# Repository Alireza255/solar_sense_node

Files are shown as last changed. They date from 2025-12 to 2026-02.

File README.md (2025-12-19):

# 🌞 Solar Sense Node

A **portable solar measuremnet unit** designed to work alongside **IV-curve tracing systems**, providing accurate environmental and panel-related measurements that complement **IV-curve tracing systems**.

This device wirelessly transmits real-time measurement data to a **IV-curve tracer unit**, enabling accurate data interpretation.

---

## 🚀 Project Overview

Accurate IV-curve measurement of solar panels requires precise knowledge of environmental conditions at the time of measurement. This project addresses that need by introducing a **dedicated wireless solar sensor module** that:

* Measures **solar irradiance** directly at the panel location
* Monitors **solar panel temperature**
* Determines **panel tilt angle**
* Sends all collected data wirelessly to the IV-curve measurement device

---

## 🔧 Measured Parameters

| Parameter | Description |
| --- | --- |
| ☀️ Solar Irradiance | Measures incident solar power for accurate performance normalization |
| 🌡️ Panel Temperature | Captures real-time module temperature for IV-curve correction |
| 📐 Tilt Angle | Determines panel orientation relative to the horizon |

---

## 🎯 Design Goals

* ✔️ High measurement accuracy
* ✔️ Low power consumption
* ✔️ Robust outdoor operation
* ✔️ Simple to use
* ✔️ Seamless integration with the IV-curve tracer developed by the team

---

## 🧪 Use Cases

* Solar panel characterization and testing
* PV system diagnostics
* Performance comparison under varying environmental conditions

---

## 🏫 Research & Development

This project is being developed by researchers at:

**University of Tehran**
**IV Curve Research Group**

The work aims to advance **practical, field-deployable measurement tools** for photovoltaic research and industrial applications.

---

## 📌 Project Status

> 🚧 **Under active development**
> Hardware design, firmware development, and system integration are currently in progress.

---

## 📜 License

This project is intended for **research and academic use**. Licensing details will be added in future releases.

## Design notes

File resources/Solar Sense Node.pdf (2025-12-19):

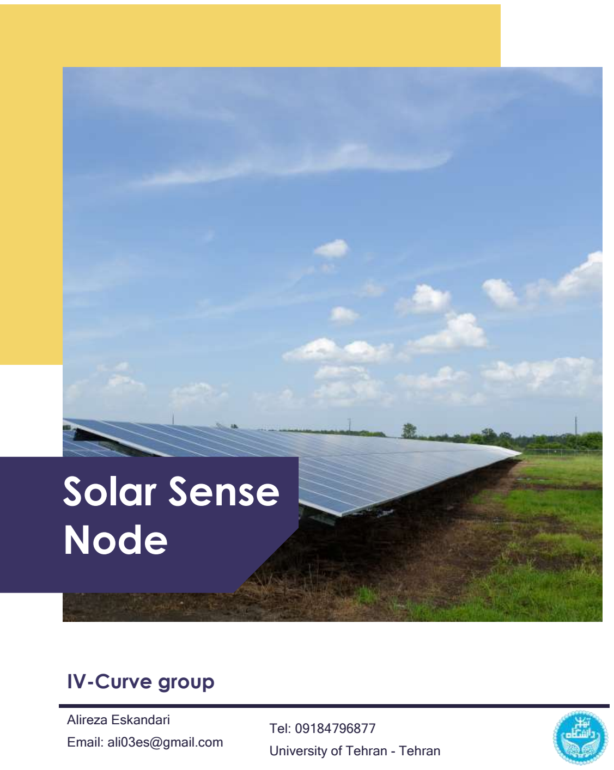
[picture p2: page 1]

# Solar Sense Node

## IV-Curve group

Alireza Eskandari

Email: ali03es@gmail.com

Tel: 09184796877

University of Tehran - Tehran

2

# DESIGN SPECIFICATIONS

1. Battery powered
2. Fully portable
3. Battery life 8 hours or longer
4. The ability to measure solar panel temperature
5. The ability to measure solar panel inclination
6. The ability to measure solar irradiance
7. Transmit telemetry data to the main device or a computer
8. Wireless link range 100 meters or greater
Spec | Solar 03 | Proposed solution
Battery life | 24hours | 30hours or higher
Tilt angle range & accuracy | 1˚-90˚ ±(1.0% + 1°) | 1˚-90˚ ±1˚
Module temperature range & accuracy | -40.0°C -99.9°C ±(1.0% + 1°C) | -55°C to +125°C ±0.5°C
Irradiance sensor range & accuracy | 0-1400 W m² ±(1.0% + 3dgt) | To be determined

The following report illustrates the different parts of the project and why each one was selected.

In addition to the information presented in this document, the link to the GitHub page of the project can be found here (https://github.com/Alireza255/solar_sense_node) and below.

github.com/Alireza255/solar_sense_node

3

Choosing a box

The sensor box, being a portable device, requires a box with a form factor that suits the

portable nature of the device.

The proposed box after careful research can be seen in the picture below:

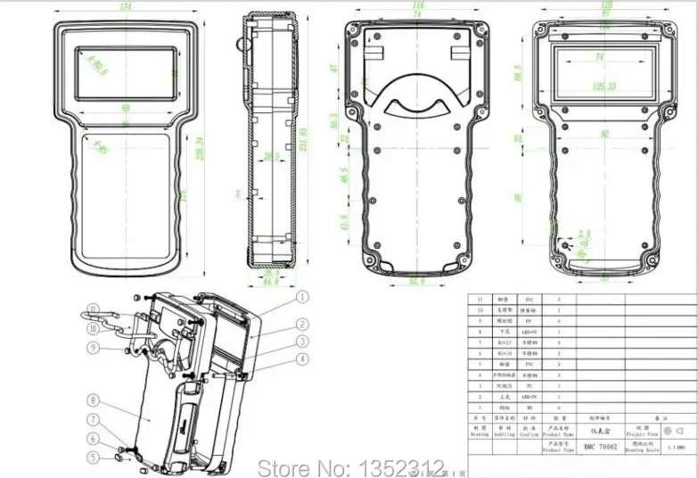
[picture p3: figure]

Mechanical specifications:

- Material: ABS plastic
- Overall dimensions: 238 × 134 × 58 mm
- Weight: 310 g (excluding screws)
- Front panel cutout size: 88 × 44 mm

The ability to implement a screen and also buttons for user interface. There are also

designated flat spots on the top and bottom for mounting connectors.

4

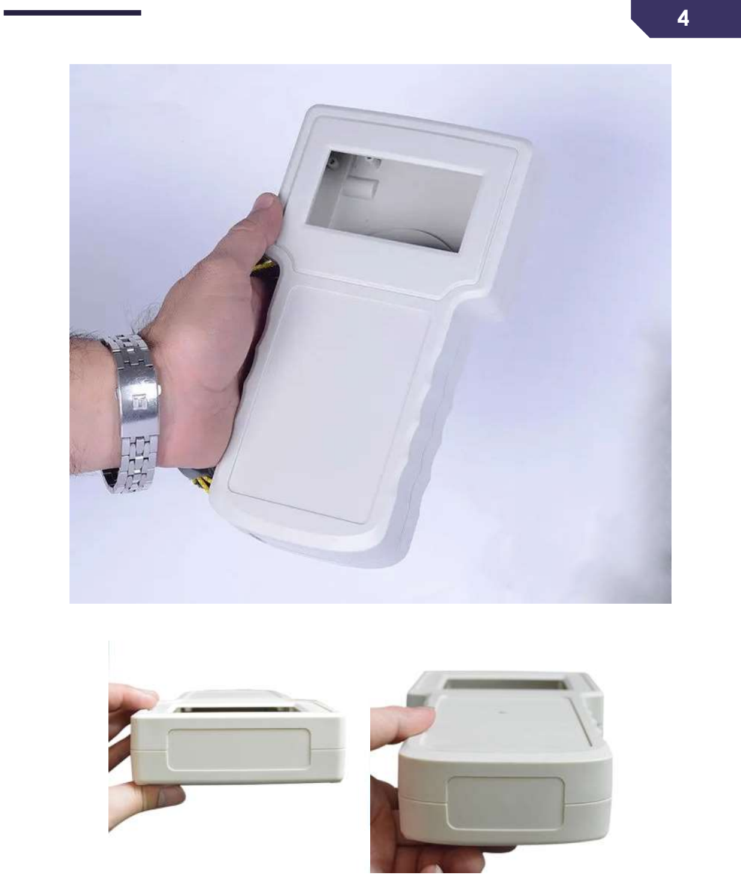
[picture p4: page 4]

5

Choosing a wireless link

After careful consideration of the constraints and available options. LoRa was chosen for

communication between the sensor box and the main box.

Why LoRa Was Selected

The sensor box system is battery powered and requires maximum wireless range and high

reliability under all environmental conditions. LoRa was selected because it provides

exceptional range while operating at very low power levels. Using chirp spread spectrum

modulation, LoRa maintains reliable communication over long distances, including non-line-

of-sight and interference-prone environments.

Unlike short-range technologies, LoRa is optimized for low data rate, low duty-cycle sensor

applications, allowing long battery life without sacrificing range.

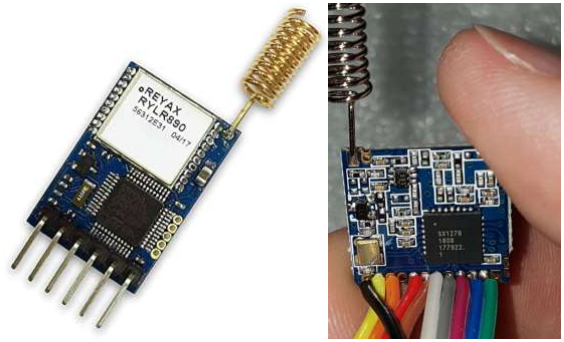
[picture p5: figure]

A comparison is made in the following table to illustrate the differences between the different

communication links that are available for this application and why LoRa is the best for our

application.

6

Technology | Typical Range | Power
| | Consumption
Data Rate | Notes
LoRa | 500m–15 km | Very Low | Very Low | High link budget, robust in harsh environments
Bluetooth | 10–100 m | Very Low | Medium | Short range, sensitive to obstacles
Zigbee | 50–200 m | Low | Low | Mesh required for long range
Wi-Fi | 50–100 m | High | High | Not suitable for battery operation
Sub-GHz FSK | 300–1000 m | Low–Medium | Low | Lower sensitivity than LoRa
Cellular | km+ | Medium–High | Medium | Requires SIM and network dependent

It is important to note that the low data rate of the LoRa protocol will never be an issue

because the amount of data that needs to be transmitted is extremely small.

Choosing a microcontroller

ARM microcontrollers, specifically those from ST-Microelectronics are very well suited for

portable applications due to their low power requirements. Another reason being that ST

offers a wide range of different microcontrollers (MCUs) for almost any application.

Research by the author indicates that microcontrollers with built-in radio links exist and

considering the requirements of the project, STM32WLE5CCU6 stands out as the perfect

choice as it includes LoRa out of the box.

This eliminates the need to add a different module on the board, simplifying the design and

freeing up more room for other components.

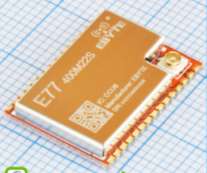
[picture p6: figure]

Ready-made modules are available which already include

everything that is needed to run the microcontroller.

This will greatly simplify the design process.

7

Communication Antenna

Any radio link needs an antenna and LoRa is no exception. In general, two different types of

antennae are suitable for our application, both of which can be seen in the figures below.

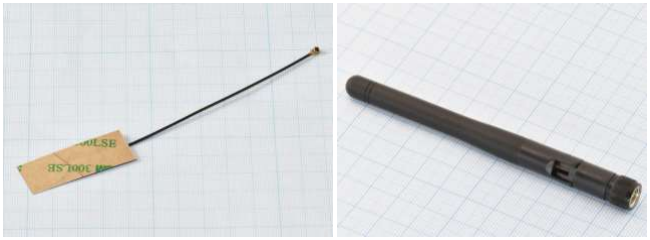
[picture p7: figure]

The antenna on the left is a patch antenna which can be installed within the device encloser

itself while the antenna on the right is a monopole antenna. Both designed for 433MHz.

One drawback to the patch antenna is directionality. Which tends to be more focused in patch

antennae. This makes communication harder since the orientation of the transmitter and

reciver in relation to one another might not be ideal.

- While the benfit of the patch antenna is clear, testing with both antenna might be

required in order to determine if the patch antenna is sufficient or not.

Power supply

In order to increase efficiency and improve battery life, great emphasis was put on having

only one supply rail in the entire device and since the MCU, wireless link and most of the

other components are powered by 3.3V, a decision was made from the very start to choose

the remaining components in such a way that they will also be powered from 3.3V.

Regulating the battery voltage down to 3.3V using a linear regulator was chosen because of

its simplicity and also the absence of much benefits if the design was to use a switching

regulator.

Choosing the right regulator required careful consideration of multiple factors, one of them

being the quiescent current which is a measure of the current draw when the output current of

8

the regulator is zero. This is extremely important as a low current draw when the micro

controller is in sleep mode will mean a higher battery life when the device is not in use.

Now a question might arise; Why not just use a switch to allow the user to turn off the device?

The answer lies in the real-time-clock of the microcontroller, which keeps time and date at the

expense of a few uA of current. Safe to say it is completely worth it.

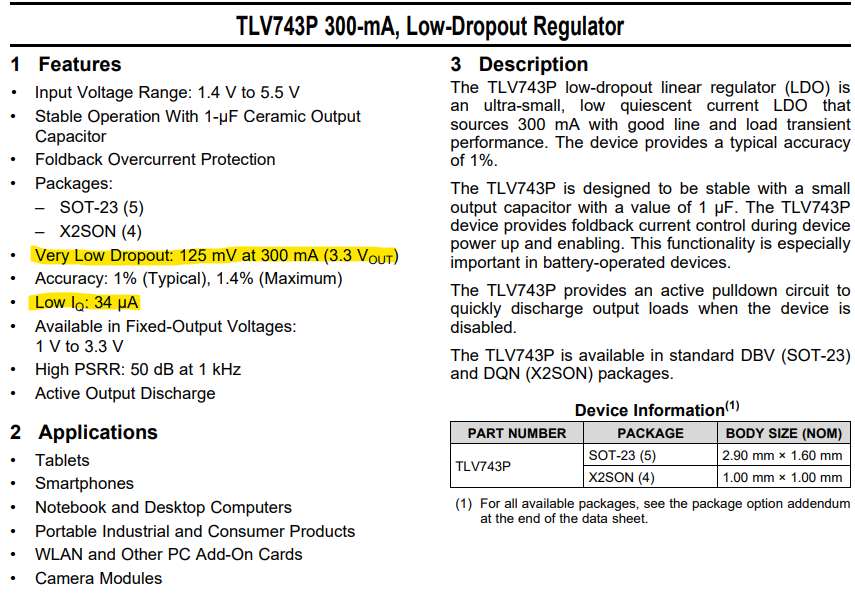
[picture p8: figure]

The chosen regulator can be seen on the picture above. This comes with the benefit of

allowing the microcontroller to turn the regulator off which means we can turn sensors or any

other parts of the circuit when needed to reduce power draw.

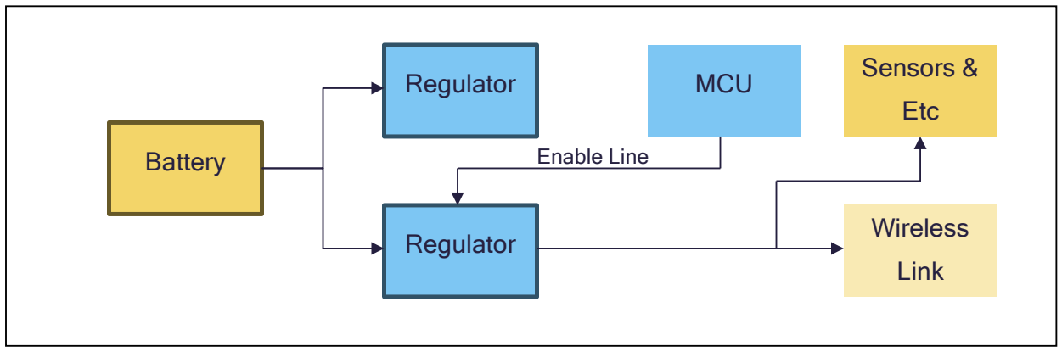
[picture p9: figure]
Battery; Regulator; MCU; Sensors &; Etc; Wireless; Link; Enable Line

9

Battery and charging

Lithium polymer batteries in the common size 18650 were chosen to power the device due to

their commonality.

Flat cells can also be used if the project runs into space

constraints, which is unlikely.

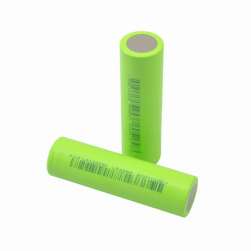
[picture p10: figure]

Charging the battery will be done using a USB-C Li-Po battery charger module which will also

provide the necessary voltage and current protections such as over-current, over-voltage and

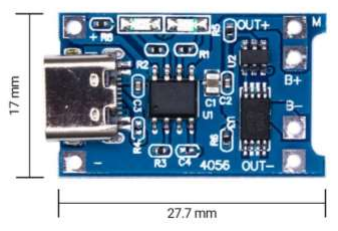
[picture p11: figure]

under-voltage protection.

An off the shelf, proven solution was

chosen instead of developing one from

scratch, saving on time and increasing

reliability.

Panel temperature sensor(s)

An interesting approach to panel temperature measurement was chosen. Instead of using

analog sensors and having to deal with accuracy problems of analog circuits, noise

susceptibility and most importantly and the current draw of analog sensors, the decision was

made to use digital sensors.

10

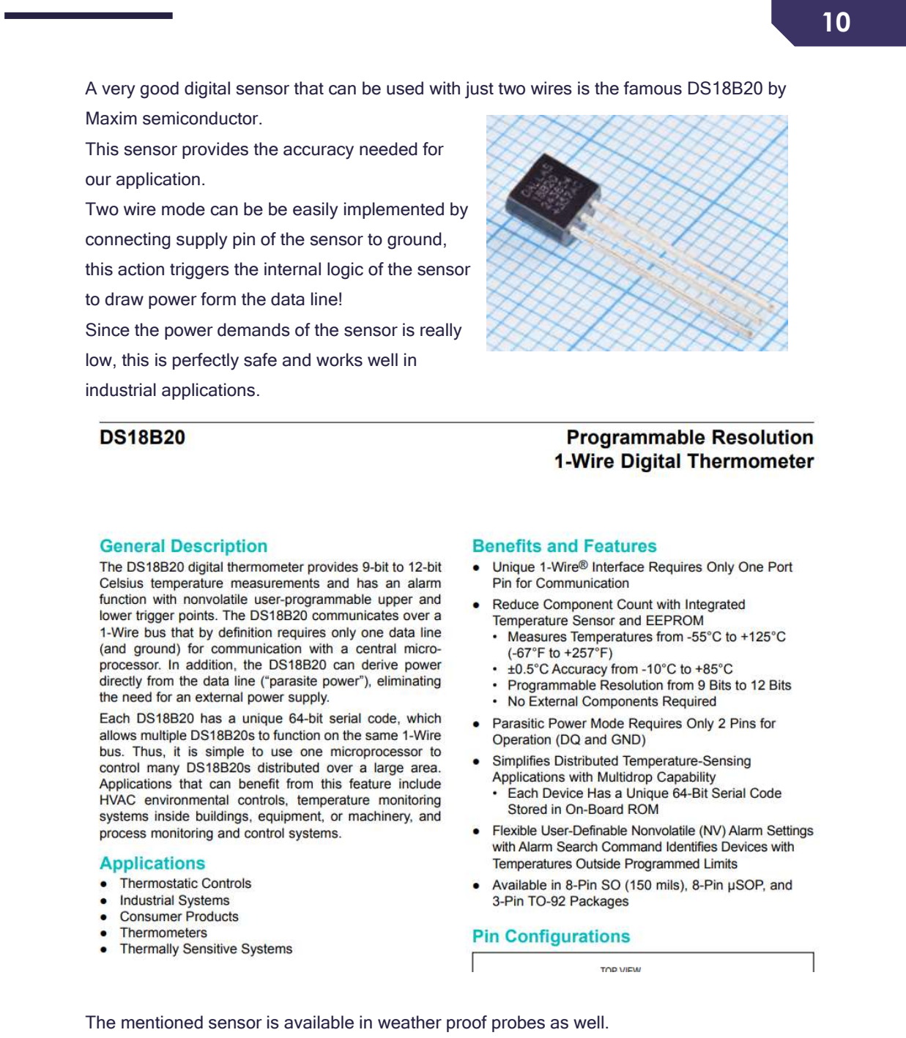
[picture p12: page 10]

A very good digital sensor that can be used with just two wires is the famous DS18B20 by

Maxim semiconductor.

This sensor provides the accuracy needed for

our application.

Two wire mode can be be easily implemented by

connecting supply pin of the sensor to ground,

this action triggers the internal logic of the sensor

to draw power form the data line!

Since the power demands of the sensor is really

low, this is perfectly safe and works well in

industrial applications.

The mentioned sensor is available in weather proof probes as well.

11

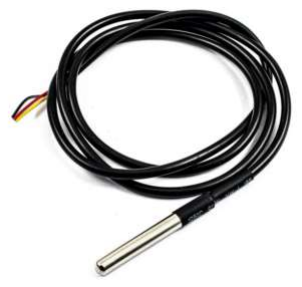
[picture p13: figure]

Each sensor has a unique 64-bit identification code which allows many sensors to be

connected on the same bus. Both parasite power and multiple sensor capability are illustrated

on the figure below.

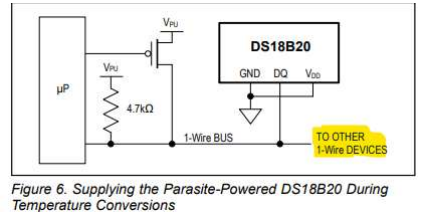
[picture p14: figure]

Panel tilt angle measurement

Another important variable that commercial devices similar to the one we are building

measure is panel tilt angle. Which can be measured using an accelerometer.

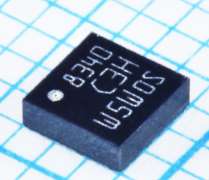
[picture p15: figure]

Since the accuracy requirements are not very strict, a

simple accelerometer by the part number LIS3DHTR was

chosen.

12

By using sensor data and calculating where the gravity acceleration vector is pointing, the

angle of the device can be calculated.

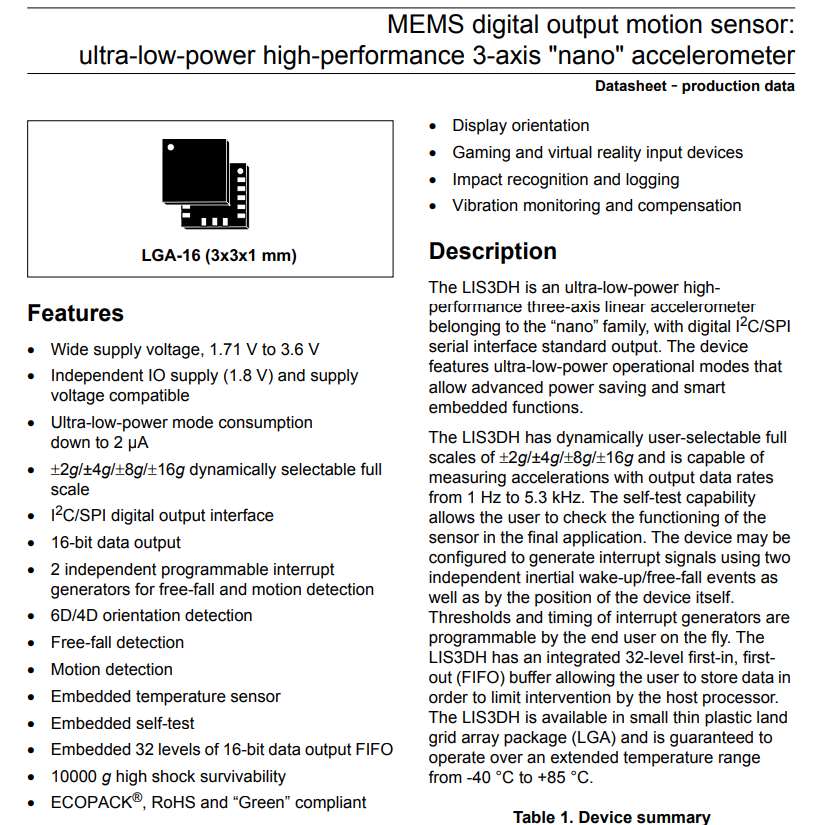
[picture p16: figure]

Solar irradiance sensor

The solar irradiance sensor used in the reference product Solar-03 made by HT Instruments

is an external reference solar cell that is very well characterized and tested. Solar-03 then

measures the current generated by the panel and correlates that to a solar irradiance number.

13

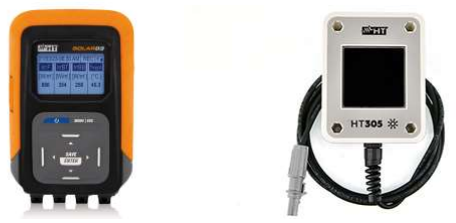
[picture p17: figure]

The irradiance sensor can be seen on the right which has internally stored calibration data

which the Solar-03 uses to calculate the solar irradiance. The basic specs can be found in the

table below.

- Measuring range: 100 ÷ 1400W/m²
- Basic accuracy: ±3.0% reading
- Type of cell: Monocrystalline
- FOV angle: >160°
- IP rating: IP65 according to IEC/EN60529
- Output connector: custom 5-pin HT connector
- Connection cable: approx. 2m
- Dimensions (WxDxH): 111x85x28mm
- Weight: 240g
- Internally stored calibration parameters

More time seems to be required in order to choose the right sensor. This is mainly the result

of few available options if we decide to go the buying route and the difficulty of molding and

characterizing a reference cell by ourselves if we decide to go the DIY route.

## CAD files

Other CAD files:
resources/boxes/BMC-70002-C1.dwg

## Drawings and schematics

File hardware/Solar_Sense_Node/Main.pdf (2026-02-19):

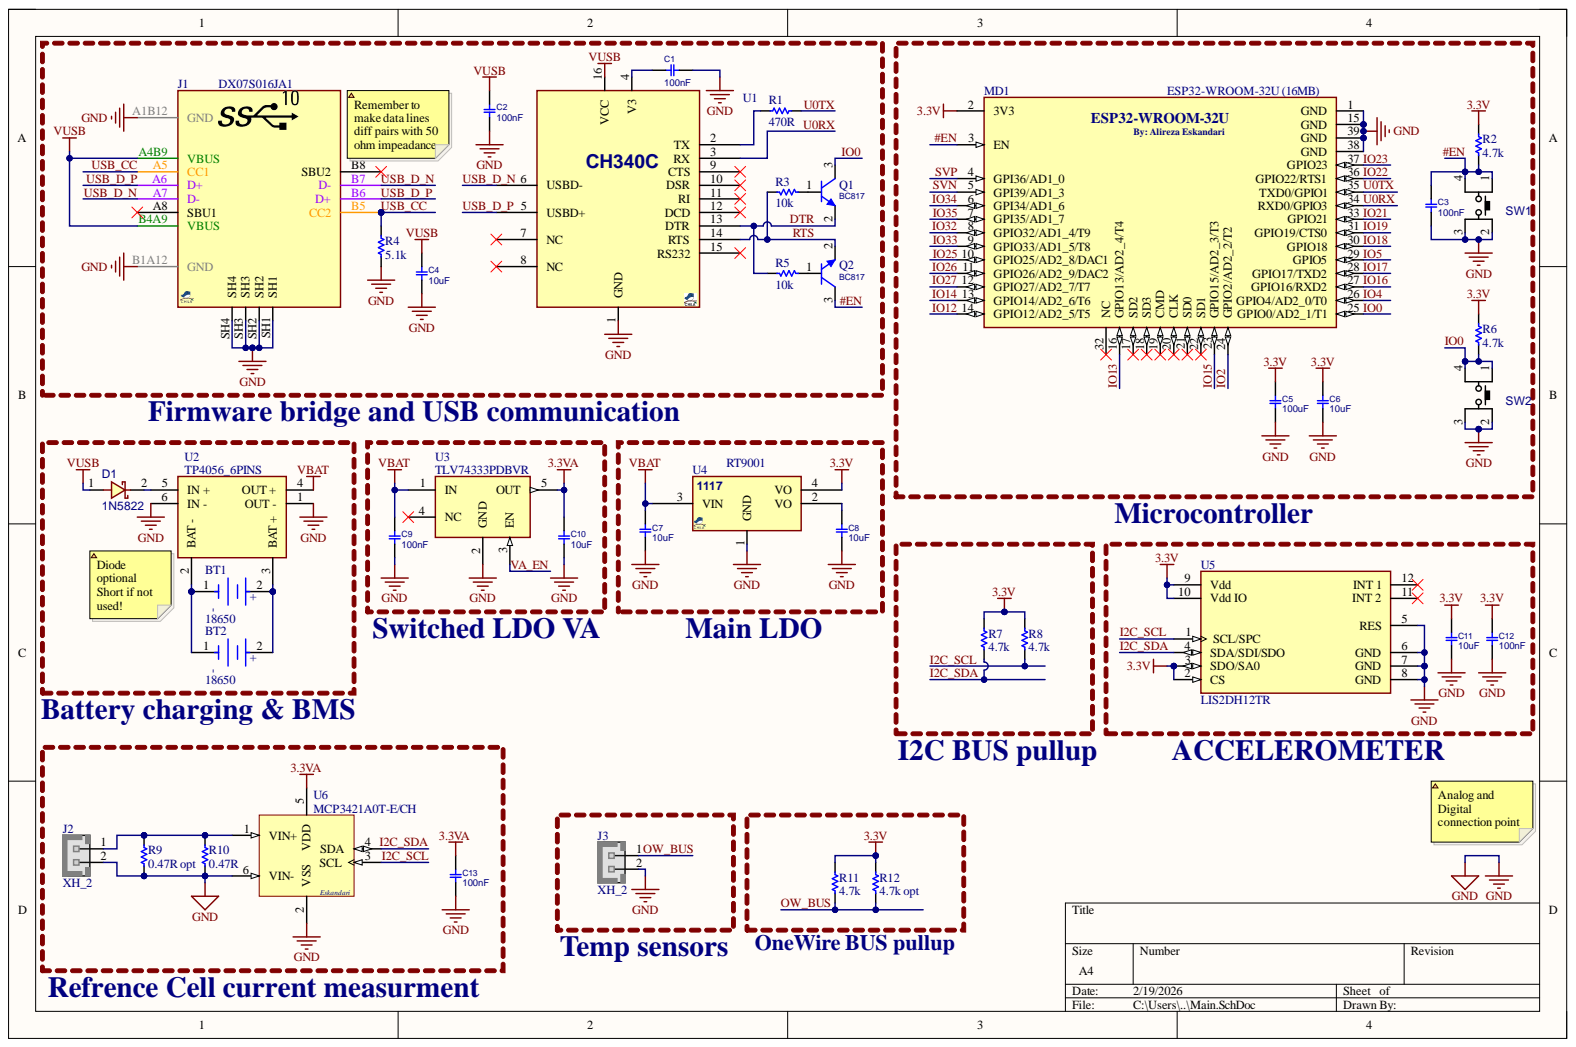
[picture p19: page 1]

ESP32-WROOM-32U By: Alireza Eskandari

Firmware bridge and USB communication

Refrence Cell current measurment

Date: 2/19/2026 | Sheet of
File: C:\Users\..\Main.SchDoc | Drawn By:

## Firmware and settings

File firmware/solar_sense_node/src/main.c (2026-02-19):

#include <string.h>
#include "freertos/FreeRTOS.h"
#include "freertos/task.h"

#include "esp_wifi.h"
#include "esp_event.h"
#include "esp_netif.h"
#include "nvs_flash.h"
#include "esp_log.h"

#include "driver/gpio.h"
#include "esp_http_server.h"

#define WIFI_SSID      "ESP32_Test"
#define WIFI_PASS      "12345678"
#define MAX_STA_CONN   4
#define LED_GPIO       GPIO_NUM_2   // Built-in LED

static const char *TAG = "WIFI_LED";

// HTML page served to phone
static const char* html_page = "<!DOCTYPE html>"
"<html>"
"<head><title>ESP32 LED Control</title></head>"
"<body>"
"<h2>LED Control</h2>"
"<button onclick=\"fetch('/on')\">ON</button>"
"<button onclick=\"fetch('/off')\">OFF</button>"
"</body>"
"</html>";

// LED control handlers
esp_err_t led_on_handler(httpd_req_t *req) {
    gpio_set_level(LED_GPIO, 1);
    httpd_resp_sendstr(req, "LED ON");
    return ESP_OK;
}

esp_err_t led_off_handler(httpd_req_t *req) {
    gpio_set_level(LED_GPIO, 0);
    httpd_resp_sendstr(req, "LED OFF");
    return ESP_OK;
}

esp_err_t root_get_handler(httpd_req_t *req) {
    httpd_resp_sendstr(req, html_page);
    return ESP_OK;
}

// Setup HTTP server
httpd_handle_t start_webserver(void) {
    httpd_config_t config = HTTPD_DEFAULT_CONFIG();
    httpd_handle_t server = NULL;
    if (httpd_start(&server, &config) == ESP_OK) {
        // URI handlers
        httpd_uri_t root = {
            .uri       = "/",
            .method    = HTTP_GET,
            .handler   = root_get_handler,
            .user_ctx  = NULL
        };
        httpd_register_uri_handler(server, &root);

        httpd_uri_t on_uri = {
            .uri       = "/on",
            .method    = HTTP_GET,
            .handler   = led_on_handler,
            .user_ctx  = NULL
        };
        httpd_register_uri_handler(server, &on_uri);

        httpd_uri_t off_uri = {
            .uri       = "/off",
            .method    = HTTP_GET,
            .handler   = led_off_handler,
            .user_ctx  = NULL
        };
        httpd_register_uri_handler(server, &off_uri);
    }
    return server;
}

// Wi-Fi AP setup (same as before)
static void wifi_event_handler(void* arg,
                               esp_event_base_t event_base,
                               int32_t event_id,
                               void* event_data) {
    // Optional: LED blink on Wi-Fi connect
}

void wifi_init_softap(void) {
    esp_netif_init();
    esp_event_loop_create_default();
    esp_netif_create_default_wifi_ap();

    wifi_init_config_t cfg = WIFI_INIT_CONFIG_DEFAULT();
    esp_wifi_init(&cfg);

    wifi_config_t wifi_config = {
        .ap = {
            .ssid = WIFI_SSID,
            .ssid_len = strlen(WIFI_SSID),
            .password = WIFI_PASS,
            .max_connection = MAX_STA_CONN,
            .authmode = WIFI_AUTH_WPA_WPA2_PSK,
            .channel = 1
        },
    };

    if (strlen(WIFI_PASS) == 0) wifi_config.ap.authmode = WIFI_AUTH_OPEN;

    esp_wifi_set_mode(WIFI_MODE_AP);
    esp_wifi_set_config(WIFI_IF_AP, &wifi_config);
    esp_wifi_start();

    ESP_LOGI(TAG, "Wi-Fi AP started. SSID:%s password:%s", WIFI_SSID, WIFI_PASS);
}

// Main application
void app_main(void) {
    // NVS
    nvs_flash_init();

    // LED
    gpio_reset_pin(LED_GPIO);
    gpio_set_direction(LED_GPIO, GPIO_MODE_OUTPUT);
    gpio_set_level(LED_GPIO, 0);

    // Start Wi-Fi AP
    wifi_init_softap();

    // Start web server
    start_webserver();

    while(1) {
        vTaskDelay(pdMS_TO_TICKS(1000));
    }
}

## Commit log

2026-02-19 schematic development and migration to ESP32 platform
    [Main.SchDoc, PCB1.PcbDoc, Solar_Sense_Node.PrjPcb]
2026-02-19 Irradiance sensors and Boxes added
2026-02-27 schematic fixes
    [BMC-70002-C1.dwg, Main.SchDoc, Solar_Sense_Node.PrjPcb]
